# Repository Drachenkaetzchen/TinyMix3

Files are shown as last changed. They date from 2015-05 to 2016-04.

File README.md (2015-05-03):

# TinyMix3

TinyMix3 is a very small, 3 channel stereo audio mixer for your pocket. It features touch and USB control and is meant
to be powered by USB. 

## Features

- Very low power consumption (<50mA). Can be powered by an USB Power Bank
- USB powered
- Touch control
- USB control (presented as serial interface to the host)

## Purpose

You can use TinyMix3 to:

- Automate 3 channel stereo mixing
- Mix 3 stereo channels on the go, ideal for musicians who don't want to carry around bulky mixers

## Usage

Manual mixing

- Connect your inputs and your output
- Touch the "CH" button to switch between the three input channels. The selected channel is indicated via the LEDs.
- After a second, TinyMix3 indicates the volume for the selected channel
- You can then use the + and - touch buttons to adjust the volume
- After 10 seconds, the LEDs turn off to save power

Automatic mixing

- Connect to the TinyMix3 using a serial terminal
- TBD: Which commands the TinyMix3 supports

## Design

Heart of the TinyMix3 is the TDA7448. It is a 6 channel mono / 3 channel stereo mixer controlled via I²C. For combining
the 3 stereo channels into a single stereo output, the TS912 rail-to-rail OpAmp is used. The main logic is implemented
using an Atmega8, which uses V-USB to provide USB control. It also implements the touch interface and controls the LEDs
on the front panel.

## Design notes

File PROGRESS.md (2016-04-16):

# 2016-03-16

Checked PSU voltages, +5V and +9V are OK. Missing µC, next time fit all components and test if the circuit works.

Probably replace the 90° connectors with something else. but FPC seems to be too expensive…

Probably replace TS912 with TS922 because it can drive headphones.

Move D3 closer to the inside of the board to avoid short circuits.

# 2016-03-18

Problems spotted:

* Mixing resistors in the outputs (10k) plus feedback opamp resistor (10k) missing
* Footprint of line jacks are mirrored, needs fixing
* Mixer doesn't mix, check out why

# 2016-03-26

* Changed mirrored connectors

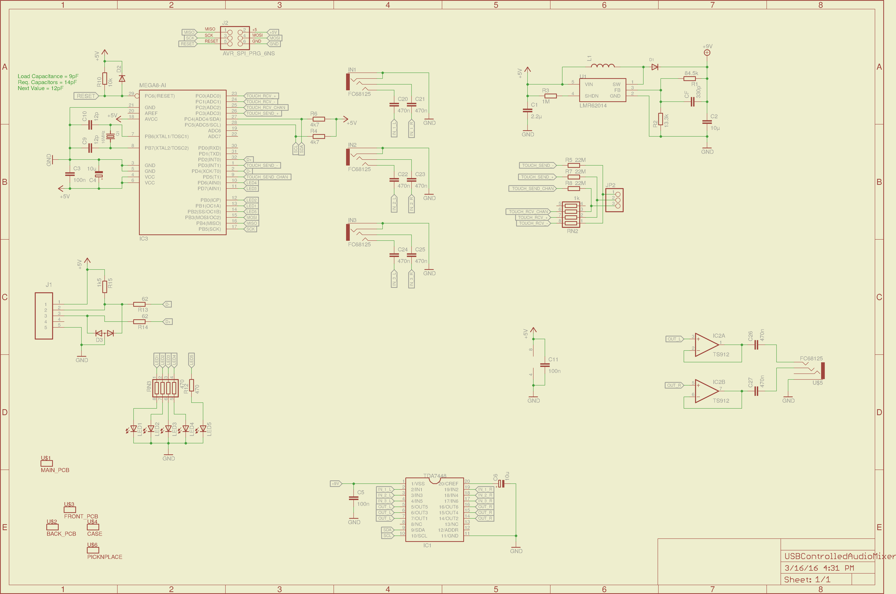
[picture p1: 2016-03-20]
USBControlledAudioMixer_sheet1.png

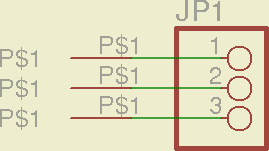
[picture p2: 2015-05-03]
FrontPanel_sheet1.png

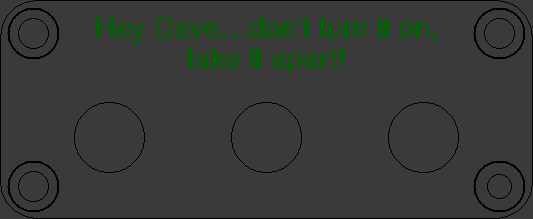
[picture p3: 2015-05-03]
BackPanel_bot.png

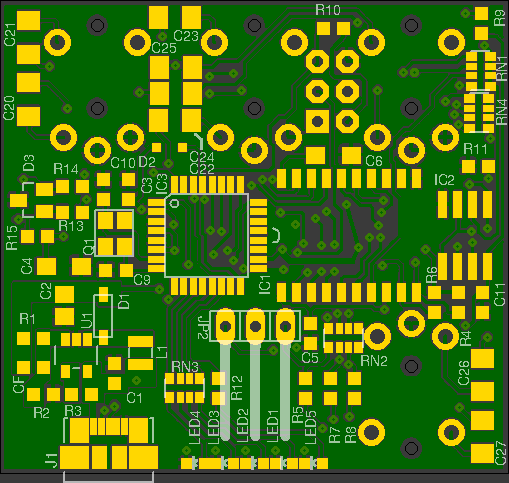
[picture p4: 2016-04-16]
USBControlledAudioMixer_top.png

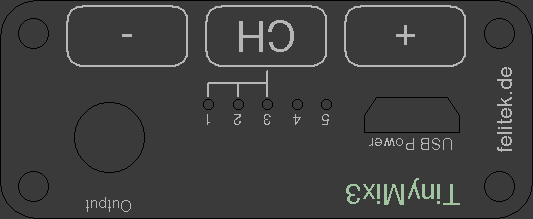
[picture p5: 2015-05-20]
FrontPanel_top.png

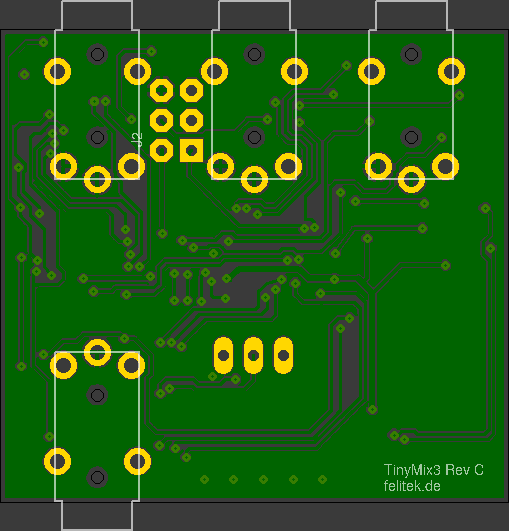
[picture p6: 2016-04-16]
USBControlledAudioMixer_bot.png

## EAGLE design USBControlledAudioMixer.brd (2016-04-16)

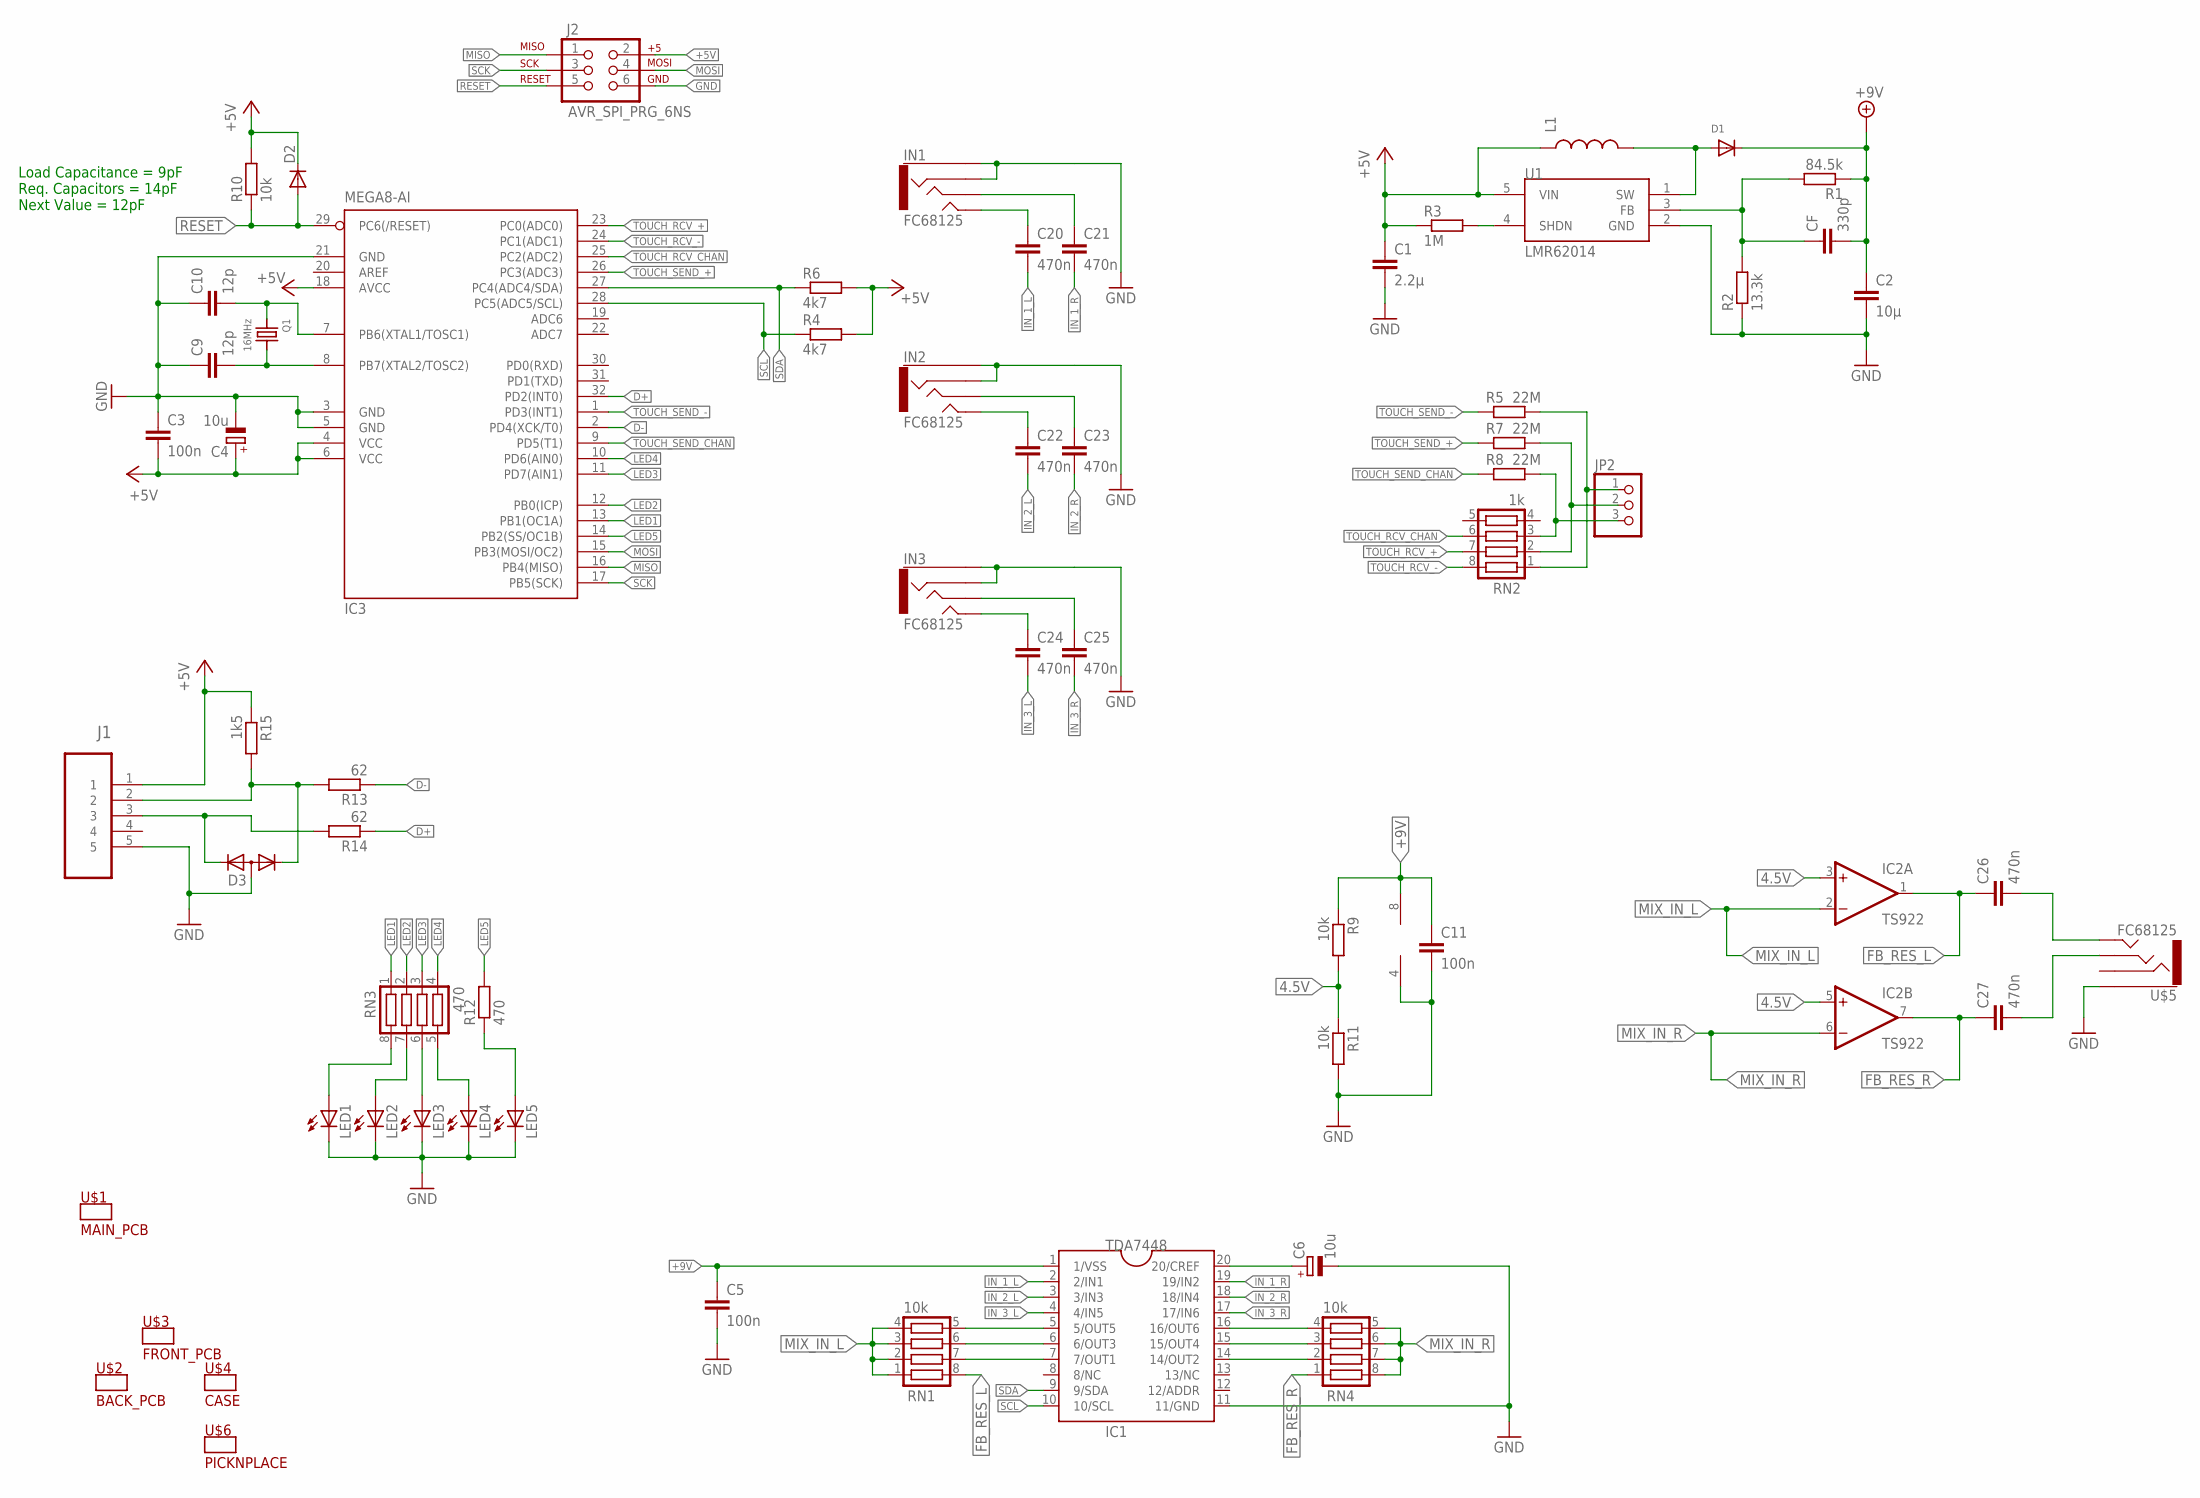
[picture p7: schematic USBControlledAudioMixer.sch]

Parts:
C1: 2.2µ; C0603
C2: 10µ; C0805
C3, C5, C11: 100n; C0603
C4, C6: 10u; SMC_A
C9, C10: 12p; C0603
C20, C21, C22, C23, C24, C25, C26, C27: 470n; C1206
CF: 330p; C0603
D1: DIODESOD-123; SOD-123
D2: DIODE-SOD323-R; SOD323-R
D3: DIODE-2CA|ACSOT23; SOT23
IC1: TDA7448; SO20
IC2: TS922; SO08
IC3: MEGA8-AI; TQFP32-08
IN1, IN2, IN3: FC68125
J1: 47346-0001; MOLEX_47346-0001
J2: AVR_SPI_PRG_6NS; 2X3-NS
JP2: PINHD-1X3; 1X03/90_MOLEX_4094
L1: INDUCTOR1007; 1007
LED1, LED2, LED3, LED4, LED5: LED0603; LED-0603
Q1: 16MHz; CRYSTAL_3.2X2.5
R1: 84.5k; R0603
R2: 13.3k; R0603
R3: 1M; R0603
R4, R6: 4k7; R0603
R5, R7, R8: 22M; R0603
R9, R10, R11: 10k; R0603
R12: 470; R0603
R13, R14: 62; R0603
R15: 1k5; R0603
RN1, RN4: 10k; YC164
RN2: 1k; YC164
RN3: 470; YC164
U1: LMR62014; SOT-23
U$5: FC68125

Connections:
4.5V: IC2.3 (+IN), IC2.5 (+IN), R9.2, R11.1
+5V: C1.1, C3.2, C4.+, D2.C, IC3.4 (VCC), IC3.6 (VCC), IC3.18 (AVCC), J1.1, J2.2, L1.1, R3.1, R4.2, R6.2, R10.2, R15.1, U1.5 (VIN)
+9V: C2.1, C5.1, C11.1, CF.2, D1.C, IC1.1 (1/VSS), IC2.8 (V+), R1.1, R9.1
D+: IC3.32 (PD2(INT0)), R14.1
D-: IC3.2 (PD4(XCK/T0)), R13.1
FB: CF.1, R1.2, R2.2, U1.3 (FB)
FB_RES_L: C26.1, IC2.1 (OUT), RN1.8
FB_RES_R: C27.1, IC2.7 (OUT), RN4.1
GND: C1.2, C2.2, C3.1, C4.-, C5.2, C6.-, C9.1, C10.1, C11.2, D3.3 (A), IC1.11 (11/GND), IC2.4 (V-), IC3.3 (GND), IC3.5 (GND), IC3.21 (GND), IN1.1, IN1.6 (2), IN2.1, IN2.6 (2), IN3.1, IN3.6 (2), J1.5, J2.6, LED1.C, LED2.C, LED3.C, LED4.C, LED5.C, R2.1, R11.2, U1.2 (GND), U$5.1
IN_1_L: C20.2, IC1.2 (2/IN1)
IN_1_R: C21.2, IC1.19 (19/IN2)
IN_2_L: C22.2, IC1.3 (3/IN3)
IN_2_R: C23.2, IC1.18 (18/IN4)
IN_3_L: C24.2, IC1.4 (4/IN5)
IN_3_R: C25.2, IC1.17 (17/IN6)
LED1: IC3.13 (PB1(OC1A)), RN3.1
LED2: IC3.12 (PB0(ICP)), RN3.2
LED3: IC3.11 (PD7(AIN1)), RN3.3
LED4: IC3.10 (PD6(AIN0)), RN3.4
LED5: IC3.14 (PB2(SS/OC1B)), R12.2
MISO: IC3.16 (PB4(MISO)), J2.1
MIX_IN_L: IC2.2 (-IN), RN1.1, RN1.2, RN1.3, RN1.4
MIX_IN_R: IC2.6 (-IN), RN4.5, RN4.6, RN4.7, RN4.8
MOSI: IC3.15 (PB3(MOSI/OC2)), J2.4
unnamed: C6.+, IC1.20 (20/CREF)
unnamed: C9.2, IC3.8 (PB7(XTAL2/TOSC2)), Q1.2
unnamed: C10.2, IC3.7 (PB6(XTAL1/TOSC1)), Q1.1
unnamed: LED1.A, RN3.8
unnamed: LED2.A, RN3.7
unnamed: LED3.A, RN3.6
unnamed: LED4.A, RN3.5
unnamed: LED5.A, R12.1
unnamed: C24.1, IN3.2 (4)
unnamed: D3.1 (K1), J1.2, R13.2, R15.2
unnamed: C25.1, IN3.3, IN3.3A (3)
unnamed: D3.2 (K2), J1.3, R14.2
unnamed: C22.1, IN2.2 (4)
unnamed: C23.1, IN2.3, IN2.3A (3)
unnamed: C20.1, IN1.2 (4)
unnamed: C21.1, IN1.3, IN1.3A (3)
unnamed: JP2.1, R5.2, RN2.1
unnamed: JP2.2, R7.2, RN2.2
unnamed: JP2.3, R8.2, RN2.3
unnamed: IC1.5 (5/OUT5), RN1.5
unnamed: IC1.6 (6/OUT3), RN1.6
unnamed: C26.2, U$5.2 (4)
unnamed: IC1.7 (7/OUT1), RN1.7
unnamed: C27.2, U$5.3, U$5.3A (3)
unnamed: IC1.16 (16/OUT6), RN4.4
unnamed: IC1.15 (15/OUT4), RN4.3
unnamed: IC1.14 (14/OUT2), RN4.2
RESET: D2.A, IC3.29 (PC6(/RESET)), J2.5, R10.1
SCK: IC3.17 (PB5(SCK)), J2.3
SCL: IC1.10 (10/SCL), IC3.28 (PC5(ADC5/SCL)), R4.1
SDA: IC1.9 (9/SDA), IC3.27 (PC4(ADC4/SDA)), R6.1
SHDN: R3.2, U1.4 (SHDN)
SW: D1.A, L1.2, U1.1 (SW)
TOUCH_RCV_+: IC3.23 (PC0(ADC0)), RN2.7
TOUCH_RCV_-: IC3.24 (PC1(ADC1)), RN2.8
TOUCH_RCV_CHAN: IC3.25 (PC2(ADC2)), RN2.6
TOUCH_SEND_+: IC3.26 (PC3(ADC3)), R7.1
TOUCH_SEND_-: IC3.1 (PD3(INT1)), R5.1
TOUCH_SEND_CHAN: IC3.9 (PD5(T1)), R8.1

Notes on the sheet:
Load Capacitance = 9pF Req. Capacitors = 14pF Next Value = 12pF

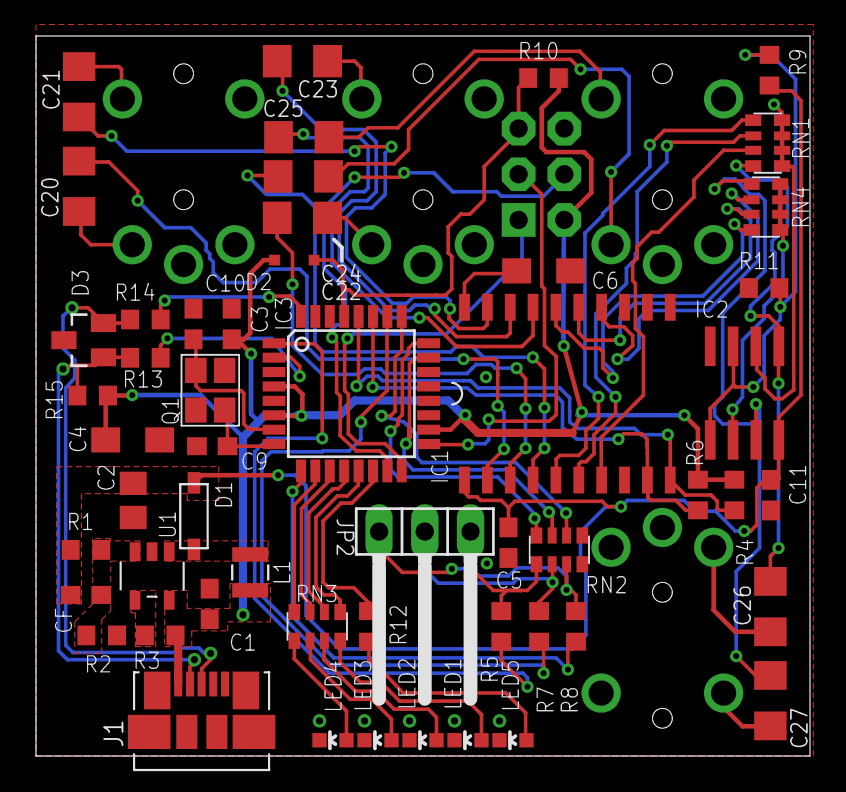
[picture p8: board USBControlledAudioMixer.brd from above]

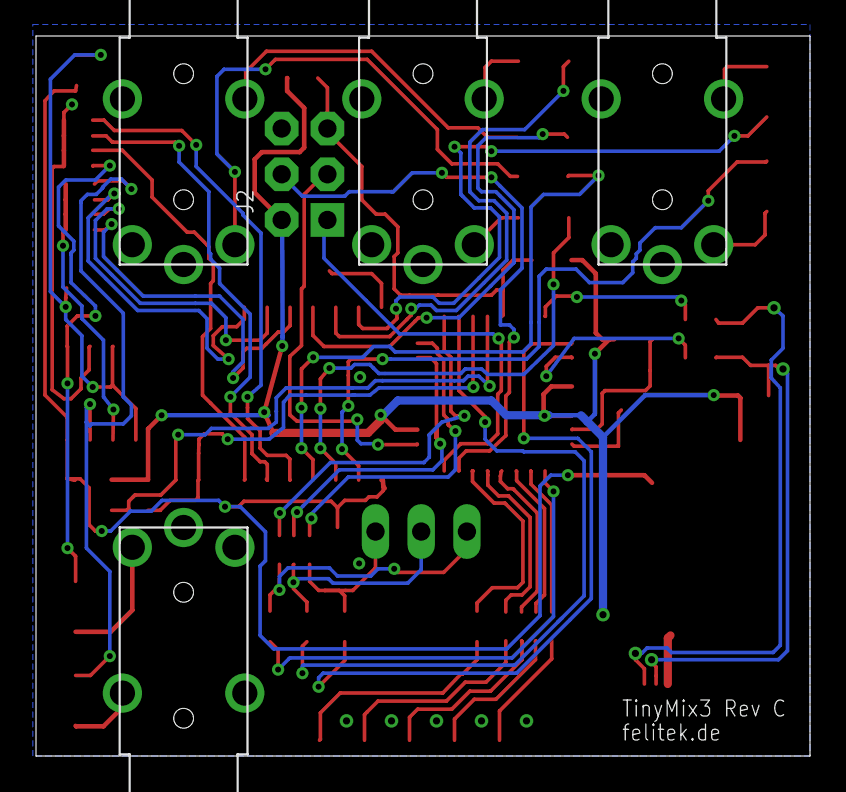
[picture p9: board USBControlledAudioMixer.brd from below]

Board: 2 copper layers, 43.0 x 40.0 mm, 58 parts (5 on the bottom side), 63 nets.

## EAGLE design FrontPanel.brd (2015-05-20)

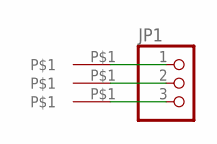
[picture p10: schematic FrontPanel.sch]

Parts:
JP1: PINHD-1X3_2.54-SMD; 1X03SMD
U$8, U$9, U$10: TOUCHPAD; TOUCH_FIELD_10X5

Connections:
unnamed: JP1.1, U$8.P$1
unnamed: JP1.2, U$9.P$1
unnamed: JP1.3, U$10.P$1

Board: 2 copper layers, 11 parts (1 on the bottom side), 3 nets.

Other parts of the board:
U$1: FC68125-FP
U$2, U$3, U$4, U$5, U$6: SMDLED_RIGHTANGLE0602
U$7: SMD-USB-PANEL

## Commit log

2015-04-20 Minor update (sorry for nonsense commit message)
    [USBControlledAudioMixer.brd, USBControlledAudioMixer.sch]
2015-04-23 Added LEDs an basic wiring
    [USBControlledAudioMixer.brd, USBControlledAudioMixer.sch]
2015-04-23 Pre-final version without proper board layout
    [USBControlledAudioMixer.brd, USBControlledAudioMixer.sch]
2015-04-25 Routing done, silkscreen adjustments missing
    [USBControlledAudioMixer.brd, USBControlledAudioMixer.sch]
2015-04-27 Initial front panel design
    [FrontPanel.brd, FrontPanel.sch]
2015-05-01 Refactored whole board because due to case layout constraint, the regular through-hole film capacitors couldn't be used anymore. We're now using 1206 SMD film capacitors.
    [FrontPanel.brd, USBControlledAudioMixer.brd, USBControlledAudioMixer.sch]
2015-05-03 Semi-finalized board, front and back panel Added 100nF capacitor for the TDA7448 mixer
    [BackPanel.brd, FrontPanel.sch, USBControlledAudioMixer.brd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]
2015-05-05 Fixed hole sizes
    [BackPanel.brd, FrontPanel.brd]
2015-05-07 Added ESD protection for the RESET line
    [USBControlledAudioMixer.brd, USBControlledAudioMixer.sch]
2015-05-20 Fixed hole size, use smaller connector for the front panel
    [FrontPanel.brd, USBControlledAudioMixer.brd, USBControlledAudioMixer.sch]
2016-03-15 Added info regarding cables
2016-03-16 Fixed capacitor order number
    [USBControlledAudioMixer.brd, USBControlledAudioMixer.sch]
2016-03-16 Corrected revision number
    [USBControlledAudioMixer.brd]
2016-04-16 Fixed audio mixing
    [USBControlledAudioMixer.brd, USBControlledAudioMixer.sch]
2016-04-16 Routed new mixer
    [USBControlledAudioMixer.brd]
2016-04-16 Fixed component labels
    [USBControlledAudioMixer.brd]

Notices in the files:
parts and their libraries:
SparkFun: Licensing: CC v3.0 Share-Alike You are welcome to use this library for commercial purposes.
